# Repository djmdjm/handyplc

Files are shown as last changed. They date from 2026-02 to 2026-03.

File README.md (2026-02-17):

# HandyPLC

This is a small PLC-like device based around a STM32F411 microcontroller.
It mostly exists because I wanted a PLC that I could program in Rust
and without vendor toolchains or closed-source libraries.

## Features and specifications

As the name suggests, HandyPLC is fairly general-purpose.

* Power supply: 24VDC nominal, 2A (worst-case). MCU power is isolated.
* Inputs: 16x isolated inputs. 5-36V
* General-purpose outputs: 16x isolated open-drain outputs. Can sink 33mA at 24V
* High-speed outputs: 4x isolated 5V logic outputs. Max 10mA.
* 3x signalling LEDs
* 3x micro-switches for UI
* USB-C interface (USB 2.0 only). Can be used for DFU.
* Spare GPIO brough out to IDC connectors and/or headers.

## Firmware

There is no standard firmware for this device. The intent is that you fork
this repository and write your own. The `firmware/` sub-directory contains
the Rust firmware that I use, but that is completely specific for my needs.

## Mechanical

The `carrier/` subdirectory contains CAD files for the holder/carrier that
I used to attach a HandyPLC to a DIN rail.

## Bugs

Probably plenty. I'm not an Electrical Engineer and have no training or
experience designing industrial devices.

Notice in particular that I have no provided any specification around the
isolation properties of this device.

Use this completely at your own risk.

## History

2026/02 - initial release (DVT 0.1)

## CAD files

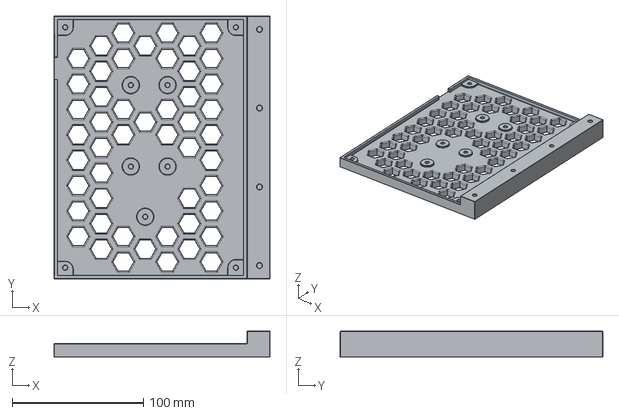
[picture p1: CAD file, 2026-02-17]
carrier/handyplc.step
164.5 x 200.0 x 19.5 mm

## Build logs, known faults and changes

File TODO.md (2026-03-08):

TO-DO list

# DVT v0.1

Errors:

* Courtyard of U5 is reversed.
* Microswitches were not populated. Error in annotation or production file prep?
* Terminal block courtyards slightly wrong; too small on one side.
* Larger silkscreen on I/O; hard to read currently
* Mounting holes are much too small.
    * They do work ok for M2.5 screws, just not M3 as intended.

Changes / improvements:

* Reconsider I/O:
    * Some relay outputs. Omron p2r-05p sockets.
    * Some on-board MOSFETs
    * Piezo status buzzer
    * Reconsider mapping of GPIOs to outputs.
        * E.g. are TIMs mapped appropriately to inputs/outputs?
    * More high-speed logic-level outputs
        * Ideally enough for step + direction for 5 axes
        * Connect to TIM channels as much as possible
        * Better physical connector too (IDC header isn't great)
    * Dedicated FAULT LED for use by panic handler?
    * More LEDs generally
        * RGB?
    * headers / JST connectors for user buttons and LEDs to allow off-board use.
    * RS-422 IO?
    * Analog IO?
* Electrical:
    * Would be nice if inputs could be made bidi again.
    * Spare GPIO headers get +5VDC too
    * TVS diodes on everything.
    * Disconnect USBPWR when MCU externally powered
        * Manual or MOSFET
    * Provision for RTC battery
    * Fuse or PTC polyfuse
* Reconsider layout
    * Reconsider board dimensions / layout
    * More blank silkscreen annotation points.
    * Avoid long traces (there's plenty...)
    * Reconsider stackup
    * Isolation
    * Impedance matching of USB
    * General ergonomics
    * Mounting holes and pinout for cheap standard OLED screen.
    * Maybe mounting holes and pinout for general daugherboard stuff

Carrier board:

* Doesn't need to be as thick
* Properly skeletonise? (current hex skeletonisation is half-assed)
* Insert nuts instead of heat-set threads?
* Make properly parametric

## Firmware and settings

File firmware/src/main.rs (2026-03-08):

#![cfg_attr(not(test), no_std)]
#![cfg_attr(not(test), no_main)]

#[cfg(not(test))]
use panic_halt as _;

use cortex_m::interrupt::Mutex;
use cortex_m_rt::entry;

use stm32f4xx_hal as hal;

use core::cell::{Cell, RefCell};

use hal::gpio::{ErasedPin, Input, Output, PinState, PushPull, Speed};
use hal::pac;
use hal::pac::interrupt;
use hal::pac::rcc::cfgr::MCO2;
use hal::prelude::*;
use hal::rcc::Config;
use hal::timer::{CounterUs, Event};
use hal::watchdog::IndependentWatchdog;

mod debounce;
mod fan;
mod morse;
mod probe;
mod servo_reset;
mod simpletimer;
mod spindle;
use debounce::Debouncer;
use fan::FanControl;
use morse::Morse;
use probe::ProbeControl;
use servo_reset::ServoResetControl;
use spindle::SpindleControl;
//use simpletimer::SimpleTimer;

const LONG_PRESS_HOLDOFF_MS: u32 = 2000;
const LONG_PRESS_HOLDON_MS: u32 = 10;

// TIM5 is configured to provide a monotonic 1kHz tick, exposed via a mutex-
// protected integer.
static G_NOW: Mutex<Cell<i64>> = Mutex::new(Cell::new(0));
static G_TIM: Mutex<RefCell<Option<CounterUs<pac::TIM5>>>> = Mutex::new(RefCell::new(None));

#[interrupt]
fn TIM5() {
    // Take static reference to counter.
    static mut TIM: Option<CounterUs<pac::TIM5>> = None;
    let tim = TIM.get_or_insert_with(|| {
        cortex_m::interrupt::free(|cs| G_TIM.borrow(cs).replace(None).unwrap())
    });

    let mut ms: i64 = 0;
    cortex_m::interrupt::free(|cs| {
        // Update monotonic millisecond counter.
        let now = G_NOW.borrow(cs);
        // Yes, this will fail after a few thousand centuries of uptime.
        // I'll fix it closer to then.
        ms = now.get() + 1;
        if ms == i64::MAX {
            panic!("timer tick overflow");
        }
        now.set(ms);
    });
    let _ = tim.wait();
}

#[cfg(not(test))]
#[entry]
fn main() -> ! {
    let dp = pac::Peripherals::take().unwrap();
    let _cp = cortex_m::peripheral::Peripherals::take().unwrap();
    let mut rcc = dp
        .RCC
        .freeze(Config::hse(25.MHz()).hclk(25.MHz()).sysclk(100.MHz()));

    let _gpioa = dp.GPIOA.split(&mut rcc);
    let _gpiob = dp.GPIOB.split(&mut rcc);
    let gpioc = dp.GPIOC.split(&mut rcc);
    let gpiod = dp.GPIOD.split(&mut rcc);
    let gpioe = dp.GPIOE.split(&mut rcc);
    let mut _delay = dp.TIM9.delay_us(&mut rcc);
    let mut timer = dp.TIM5.counter_us(&mut rcc);

    let mut watchdog = IndependentWatchdog::new(dp.IWDG);
    if false {
        dp.DBGMCU
            .apb1_fz()
            .modify(|_, w| w.dbg_iwdg_stop().set_bit());
    }

    // Start the timer to give us a 1kHz clock interrupt.
    timer.start(1.millis()).unwrap();
    timer.listen(Event::Update);
    cortex_m::interrupt::free(|cs| *G_TIM.borrow(cs).borrow_mut() = Some(timer));
    unsafe {
        cortex_m::peripheral::NVIC::unmask(pac::Interrupt::TIM5);
    }

    // TODO: move all these to a separate board support library?
    let mut leds: [Option<ErasedPin<Output<PushPull>>>; 3] = [
        Some(gpioc.pc4.into_push_pull_output().speed(Speed::Low).erase()),
        Some(gpioc.pc5.into_push_pull_output().speed(Speed::Low).erase()),
        Some(gpioc.pc13.into_push_pull_output().speed(Speed::Low).erase()),
    ];

    let mut gp_outputs: [Option<ErasedPin<Output<PushPull>>>; 16] = [
        Some(gpiod.pd0.into_push_pull_output().speed(Speed::Low).erase()),
        Some(gpiod.pd1.into_push_pull_output().speed(Speed::Low).erase()),
        Some(gpiod.pd2.into_push_pull_output().speed(Speed::Low).erase()),
        Some(gpiod.pd3.into_push_pull_output().speed(Speed::Low).erase()),
        Some(gpiod.pd4.into_push_pull_output().speed(Speed::Low).erase()),
        Some(gpiod.pd5.into_push_pull_output().speed(Speed::Low).erase()),
        Some(gpiod.pd6.into_push_pull_output().speed(Speed::Low).erase()),
        Some(gpiod.pd7.into_push_pull_output().speed(Speed::Low).erase()),
        Some(gpiod.pd8.into_push_pull_output().speed(Speed::Low).erase()),
        Some(gpiod.pd9.into_push_pull_output().speed(Speed::Low).erase()),
        Some(gpiod.pd10.into_push_pull_output().speed(Speed::Low).erase()),
        Some(gpiod.pd11.into_push_pull_output().speed(Speed::Low).erase()),
        Some(gpiod.pd12.into_push_pull_output().speed(Speed::Low).erase()),
        Some(gpiod.pd13.into_push_pull_output().speed(Speed::Low).erase()),
        Some(gpiod.pd14.into_push_pull_output().speed(Speed::Low).erase()),
        Some(gpiod.pd15.into_push_pull_output().speed(Speed::Low).erase()),
    ];

    let mut inputs: [Option<ErasedPin<Input>>; 16] = [
        Some(gpioe.pe0.internal_pull_down(true).into_input().erase()),
        Some(gpioe.pe1.internal_pull_down(true).into_input().erase()),
        Some(gpioe.pe2.internal_pull_down(true).into_input().erase()),
        Some(gpioe.pe3.internal_pull_down(true).into_input().erase()),
        Some(gpioe.pe4.internal_pull_down(true).into_input().erase()),
        Some(gpioe.pe5.internal_pull_down(true).into_input().erase()),
        Some(gpioe.pe6.internal_pull_down(true).into_input().erase()),
        Some(gpioe.pe7.internal_pull_down(true).into_input().erase()),
        Some(gpioe.pe8.internal_pull_down(true).into_input().erase()),
        Some(gpioe.pe9.internal_pull_down(true).into_input().erase()),
        Some(gpioe.pe10.internal_pull_down(true).into_input().erase()),
        Some(gpioe.pe11.internal_pull_down(true).into_input().erase()),
        Some(gpioe.pe12.internal_pull_down(true).into_input().erase()),
        Some(gpioe.pe13.internal_pull_down(true).into_input().erase()),
        Some(gpioe.pe14.internal_pull_down(true).into_input().erase()),
        Some(gpioe.pe15.internal_pull_down(true).into_input().erase()),
    ];

    // Enable to expose sysclk on MCO2.
    if false {
        rcc.cfgr().modify(|_, w| w.mco2().variant(MCO2::Sysclk));
        gpioc.pc9.into_alternate::<0>().set_speed(Speed::VeryHigh);
    }

    let _no_fault_in = inputs[11].take().unwrap();
    let _servo_do1 = inputs[13].take().unwrap();
    let _servo_do6 = inputs[14].take().unwrap();
    let _servo_do5 = inputs[15].take().unwrap();

    let mut _servo_di4 = gp_outputs[10].take().unwrap();
    let mut _servo_di5 = gp_outputs[11].take().unwrap();
    let mut _servo_dicw64 = gp_outputs[12].take().unwrap();

    // Spindle fan control.
    let spindle_run = inputs[7].take().unwrap();
    let mut fan_run = gp_outputs[0].take().unwrap();
    let mut fan_control = FanControl::default();
    let mut fan_status_led = leds[0].take().unwrap();
    let mut fan_status_morse = Morse::default();

    // Wireless touch probe control.
    let probe_enable = inputs[4].take().unwrap();
    let probe_alarm = inputs[3].take().unwrap();
    let probe_lowbatt = inputs[2].take().unwrap();
    let mut probe_power = gp_outputs[1].take().unwrap();
    let mut probe_detect = gp_outputs[2].take().unwrap();
    let mut probe_control = ProbeControl::default();
    let mut probe_status_led = leds[1].take().unwrap();
    let mut probe_status_morse = Morse::default();

    // Manual brake control.
    let cabinet_button = inputs[8].take().unwrap();
    let mut cabinet_button_debouncer = Debouncer::default();
    let mut manual_brake_state: bool = false;

    // Servo reset signal control.
    let servo_reset_in = inputs[12].take().unwrap();
    let mut servo_reset_out = gp_outputs[8].take().unwrap();
    let mut servo_reset_control = ServoResetControl::default();
    let mut cabinet_button_longpress = Debouncer::new(
        LONG_PRESS_HOLDOFF_MS.millis(),
        LONG_PRESS_HOLDON_MS.millis(),
    );

    // Spindle control.
    let mut spindle_run_out = gp_outputs[9].take().unwrap();
    let mut spindle_brake_release_out = gp_outputs[15].take().unwrap();
    let mut spindle_control = SpindleControl::default();

    // Mainloop.
    let mut heartbeat = leds[2].take().unwrap();
    let mut now_ms: i64 = 0;
    watchdog.start(1.millis());
    loop {
        cortex_m::interrupt::free(|cs| {
            now_ms = G_NOW.borrow(cs).get();
        });
        heartbeat.set_state(PinState::from(((now_ms / 2000) & 1) == 0));

        let spindle_on = spindle_run.is_high();

        // Fan control FSM.
        fan_control.update(spindle_on, now_ms);
        fan_run.set_state(PinState::from(fan_control.fan_state()));
        fan_status_morse.set_char(fan_control.status_char());
        fan_status_morse.update(now_ms);
        fan_status_led.set_state(PinState::from(fan_status_morse.output()));

        // Probe control FSM.
        probe_control.update(
            probe_enable.is_high(),
            probe_alarm.is_high(),
            probe_lowbatt.is_high(),
            now_ms,
        );
        probe_power.set_state(PinState::from(probe_control.probe_power()));
        probe_detect.set_state(PinState::from(probe_control.probe_detect()));
        probe_status_morse.set_char(probe_control.status_char());
        probe_status_morse.update(now_ms);
        probe_status_led.set_state(PinState::from(probe_status_morse.output()));

        // Servo reset control FSM.
        cabinet_button_longpress.update(cabinet_button.is_high(), now_ms);
        let reset_asserted = servo_reset_in.is_high() || cabinet_button_longpress.is_on();
        servo_reset_control.update(reset_asserted, now_ms);
        servo_reset_out.set_state(PinState::from(servo_reset_control.reset_state()));
        // Manual brake control.
        cabinet_button_debouncer.update(cabinet_button.is_high(), now_ms);
        if cabinet_button_debouncer.posedge() {
            manual_brake_state = !manual_brake_state;
        }

        // Spindle control FSM.
        let spindle_inhibit = probe_control.spindle_inhibit();
        spindle_control.update(spindle_on, spindle_inhibit, now_ms);
        spindle_run_out.set_state(PinState::from(spindle_control.spindle_on()));
        let brake_release_on = !spindle_control.brake_on() || manual_brake_state;
        spindle_brake_release_out.set_state(PinState::from(brake_release_on));

        watchdog.feed();
    }
}

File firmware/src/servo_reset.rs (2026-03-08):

//! Servo reset PLC logic
//!
//! If the my servo fault trips then it needs a reset signal to come out of
//! the fault condition. Unfortunately there's a race condition between the
//! servo's alarm output, which is asserted whenever there's a fault and is
//! used to trip the Safe Torque Off input to the servo, and my CNC
//! controller's reset output, which is deasserted a bit too quickly when
//! clearing a fault.
//!
//! The result of this is that it's impossible to reset the servo out of
//! fault - the servo reset happens before or too quickly after the CNC
//! alarm is deasserted, and the servo's alarm output instantly re-trips
//! the CNC controller.
//!
//! The solution to this is just to hold the reset signal up for long enough
//! that the CNC controller alarm has cleared.
use fugit::ExtU32;
use crate::simpletimer::SimpleTimer;

#[derive(Default)]
enum ServoResetFSMState {
    #[default]
    Off,
    On,
    HoldOn(SimpleTimer),
}

#[derive(Default)]
pub struct ServoResetControl {
    state: ServoResetFSMState,
}

const RESET_HOLDON_MS: u32 = 50;

impl ServoResetControl {
    pub fn update(&mut self, reset_on: bool, now: i64) {
        match &self.state {
            ServoResetFSMState::Off => {
                if reset_on {
                    self.state = ServoResetFSMState::On;
                }
            }
            ServoResetFSMState::On => {
                if !reset_on {
                    self.state =
                        ServoResetFSMState::HoldOn(SimpleTimer::start(now, RESET_HOLDON_MS.millis()))
                }
            }
            ServoResetFSMState::HoldOn(holdon) => {
                if reset_on {
                    self.state = ServoResetFSMState::On
                } else if holdon.expired(now) {
                    self.state = ServoResetFSMState::Off
                }
            }
        }
    }

    pub fn reset_state(&self) -> bool {
        match self.state {
            ServoResetFSMState::Off => false,
            ServoResetFSMState::On => true,
            ServoResetFSMState::HoldOn(_) => true,
        }
    }

    #[allow(dead_code)]
    pub fn status_char(&self) -> char {
        match self.state {
            ServoResetFSMState::Off => 'L',
            ServoResetFSMState::On => 'M',
            ServoResetFSMState::HoldOn(_) => 'Y',
        }
    }
}

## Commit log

2026-02-17 Initial import: DVT 0.1
    [gp_input.kicad_sch, gp_output.kicad_sch, handyplc.kicad_sch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]
2026-02-17 ignore cad backups, etc.
2026-02-17 shrink insert holes for m2.5 inserts to match DVT
2026-02-17 include .step file for easier printing
    [handyplc.step]
2026-02-20 servo reset controller
2026-02-20 servo reset control I neglected to commit earlier
    [servo_reset.rs]
2026-03-07 watchdog timer
2026-03-08 spindle control logic
    use as-wired inputs/outputs
2026-03-08 simple button debouncer and manual brake control
2026-03-08 long press cabinet button to manually reset servo
    [main.rs]
